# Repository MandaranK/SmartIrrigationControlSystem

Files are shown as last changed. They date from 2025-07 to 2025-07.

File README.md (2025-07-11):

# SmartIrrigationControlSystem
Designed on a custom-designed PCB using Proteus, integrating sensors, actuators, STM32, multivoltage rails, and display components to automate valve switching across irrigation zones. Used HAL to coordinate PWM, UART, ADC, and EXTI. Implemented timer-driven scheduling, RPM sensing, and interrupt-based logic.

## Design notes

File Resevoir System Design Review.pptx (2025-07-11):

## ECE298 Reservoir System Design Review

## Overview

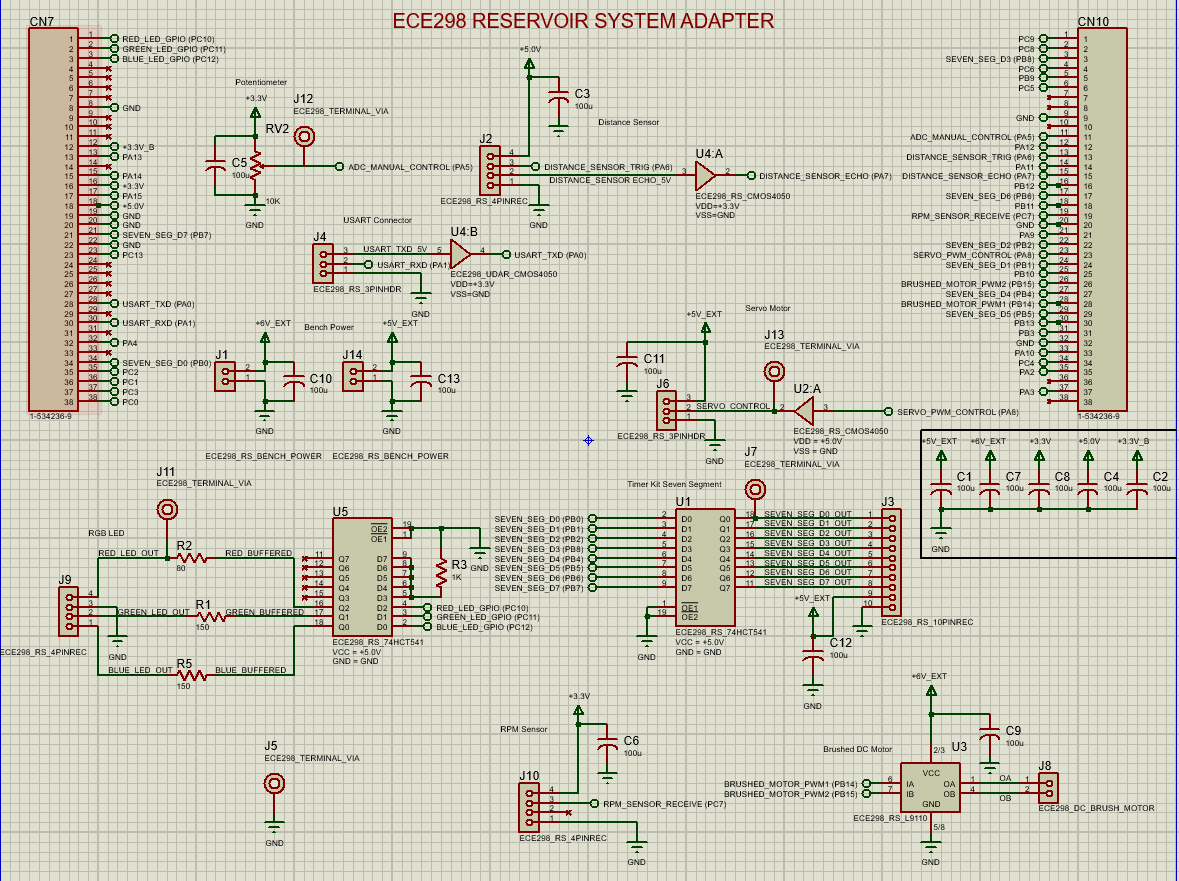
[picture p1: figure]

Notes: The reservoir system is powered by the 3.3V and 5V pins from the STM32, as well as 5V and 6V bench powers for the motors. All sensors and motors are controlled and utilized via the GPIO pins on the microcontroller. This design contains manual and terminal control for interfacing with the system, as well a display and RGB LED for visual aid. The pump for pumping water in and out of the reservoir is controlled by a brushed DC motor, and the distributer for distributing water to each of its 3 pipes is controlled with a servo. Lastly, the reservoir water level is monitored by an ultrasonic distance sensor.

## Bench Power

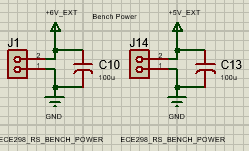
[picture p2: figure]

Operating Voltages: 5V and 6V external
Capacitors: 100 µF

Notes: There’s two connectors for external power here—6V and 5V—each with a ground. We added a capacitor across each supply to filter out noise and fluctuations from the bench power supply, ensuring steady voltage for the components. This setup helps prevent voltage drops or spikes, delivering stable power to maintain performance and protecting sensitive components.

## Power Decoupling

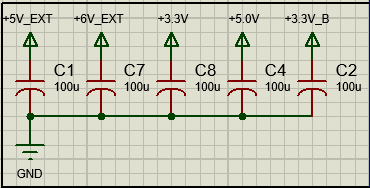
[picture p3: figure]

Operating Voltages : 3.3V, 5V, and 6V
Capacitors: 100 µF

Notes: The power decoupling uses 100 µF capacitors between ground and various voltage rails to stabilize power by filtering high-frequency noise and spikes. With different components drawing power at different times, these capacitors smooth fluctuations on each rail (5V, 6V, 3.3V). Placing them close to each rail provides localized filtering, minimizing interference or dips that could affect sensitive components.

## USART Connection

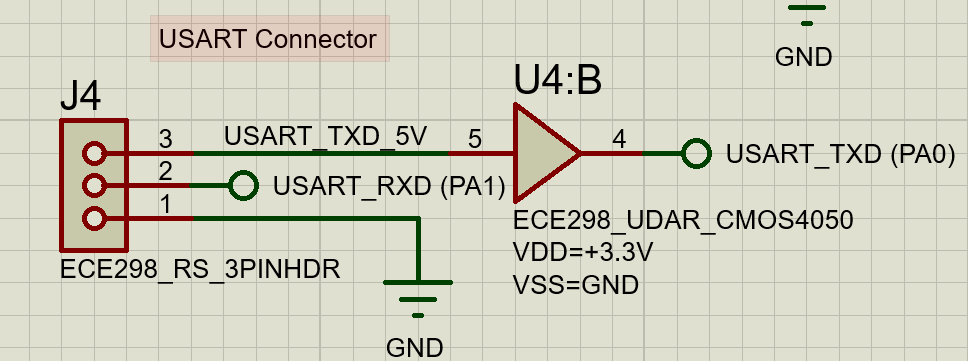
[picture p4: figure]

GPIO Pins: A0 (output), A1 (input)
Operating Voltage: 3.3V

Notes: Firstly we have the USART connnection. This allows the operator to interface
with the resevoir system via a terminal computer. This requires 2 lines: a transfer
line (TXD) and a receiving line (RXD). Since the STM32 only accepts a 3.3V input signal on
its GPIO pins, a buffer is used to translate the 5V high signal from the terminal to a 3.3V
signal on the transfer line. The USART connection can tolerate the 3.3V high signal from the MCU, so no buffer
is required on the receiving line

## Manual Control

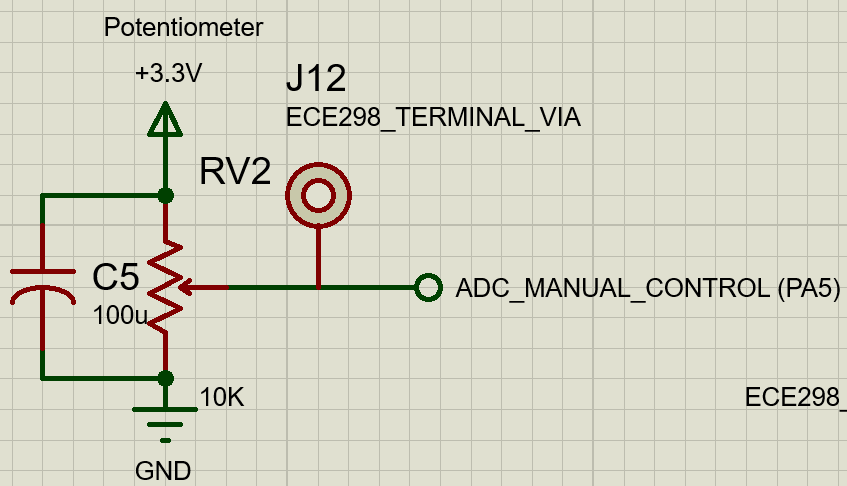
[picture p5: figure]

Output Voltage Range: 0V to 3.3V
Output Pin: A5 (ADC pin)

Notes: The potentiometer is used for manual control of the reservoir signal. A decoupled 3.3V source is applied across a variable potentiometer, which results in a variable output voltage in between 0 and 3.3V. Pin A5 is then used for its ADC capabilities to translate this voltage into an 8-bit number for use by the microcontroller. The test point can be used to ensure the correct range and values for this variable output voltage.

## Seven Segment Display Connection

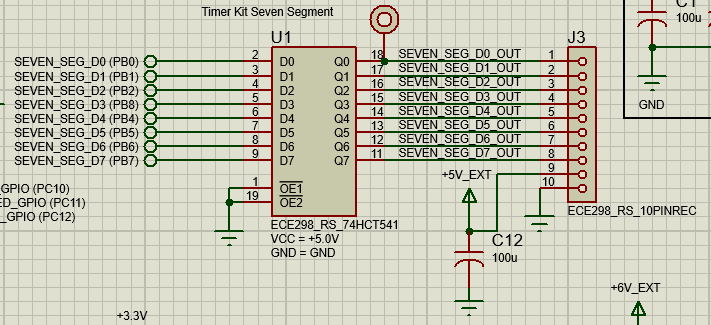
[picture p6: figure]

Timer Kit Operating Voltage: +5V
GPIO Output Pins: B0, B1, B2, B8, B4, B5, B6, B7

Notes: Next, the Timer Kit from Lab A is used for its seven-segment display. As the seven segment display requires a 5V high signal to operate, a buffer is used to translate the 3.3V signals from the MCU’s gpio pins to 5V signals. The connector to interface with the board contains 7 pins for each of the 7 segments, a 5V external pin for powering the board and a ground pin. Additionally, the test point allows the user to ensure the correct signal is reaching the timer board at all times

## RGB LED

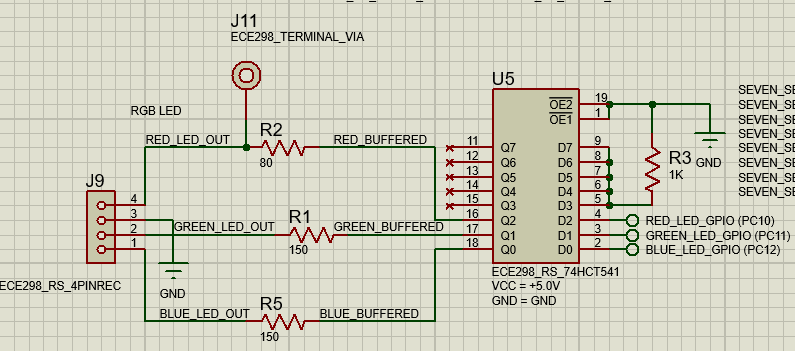
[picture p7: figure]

Operating Voltage: +5V
GPIO Output Pins: C10, C11, C12

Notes: This circuit controls an RGB LED using GPIO pins through a 74HCT541 buffer, with each LED color regulated by its own resistor (R2, R1, R5) to manage current and brightness. The buffer isolates and boosts the GPIO signals (PC10, PC11, PC12) to handle the LED’s current needs, protecting the microcontroller. Each LED is connected to a separate GPIO pin for smooth color mixing, with the buffer and LEDs powered by 5V for stable operation.

## Brushed DC Motor

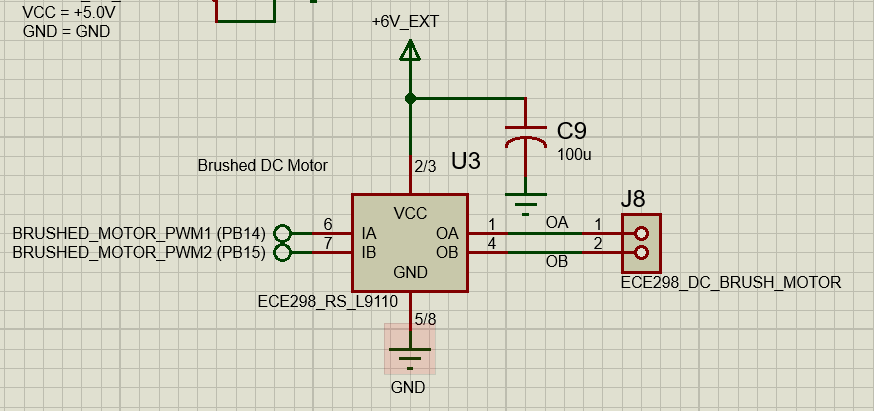
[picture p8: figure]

Operating Voltage: 6V external
GPIO Output Pins: B14, B15 (PWM pins)

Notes: This circuit controls a brushed DC motor using a motor driver powered by an external 6V supply, providing sufficient voltage without burdening the STM microcontroller. A capacitor smooths out voltage spikes, ensuring steady motor performance under load. The microcontroller’s PWM signals connect to the driver inputs, adjusting motor speed via duty cycle changes and reversing direction by toggling the inputs. The driver outputs connect to the motor terminals.

## RPM Sensor

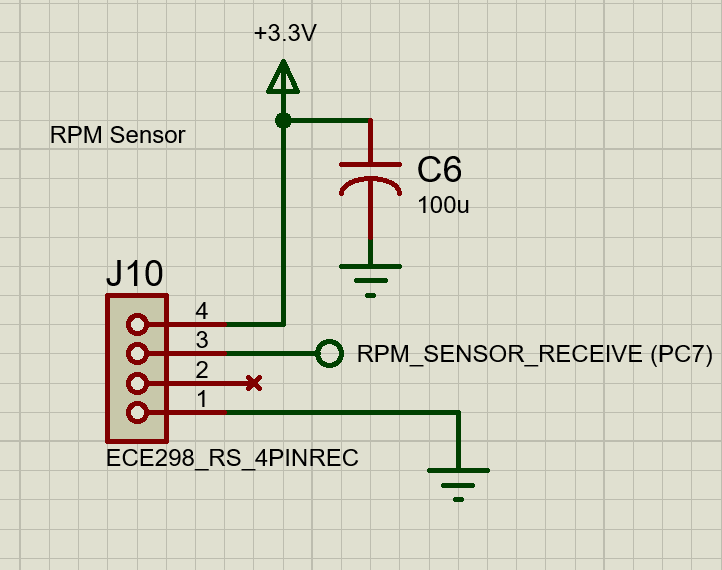
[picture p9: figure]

Operating Voltage: +3.3V
GPIO Input Pin: C7 (Receive pin)

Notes: This circuit reads RPM data from a sensor, with a stable 3.3V supply for accuracy. This 4-pin header contains a power, ground, and signal, with a 100 µF capacitor (C6) smoothing any voltage fluctuations. The sensor’s output is routed to the "RPM_SENSOR_RECEIVE" pin (PC7) for clean, reliable RPM data.

## Servo Control

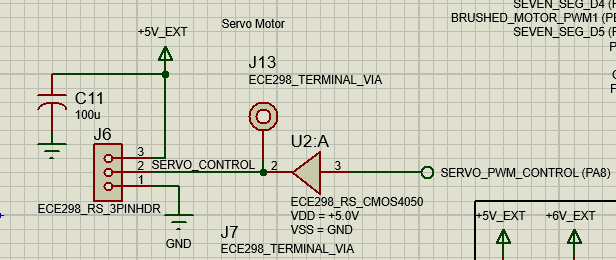
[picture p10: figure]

Operating Voltage: 5V external
GPIO Input Pin: A8 (PWM pin)

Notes: Moving on we have the servo that controls which pipe the reservoir is connected to. The servo is powered by the decoupled external 5V bench power to reduce noise. Pin A8 on the STM32 supports PWM outputs, so its 3.3V high signal is translated to a 5V high signal for PWM motor control. The additional test point can be used to monitor this translated PWM signal. The connector allows for wire connections to this translated PWM signal, the external bench power, and ground.

## Distance Sensor

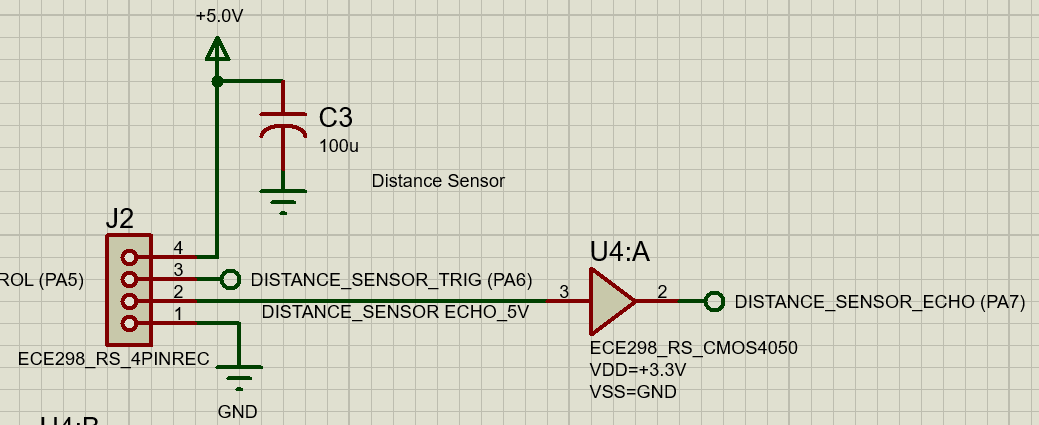
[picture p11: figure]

Operating Voltage: +5V
GPIO Pins: A6 (output), A7 (input)

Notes: Lets continue with the HCSR04 distance sensor, which monitors the water level of the reservoir. The sensor has a trigger signal for starting the collection of data, and an echo signal for the transfer of this data. A buffer is used to translate the 5V echo signal of the sensor to a 3.3V signal that complies with the STM32’s gpio pins. Since the sensor can tolerate the 3.3V high signal from the MCU, no buffer is needed. A 4 pin connector connects the decoupled 5V supply voltage, trigger, echo, and ground reference signals to the sensor.

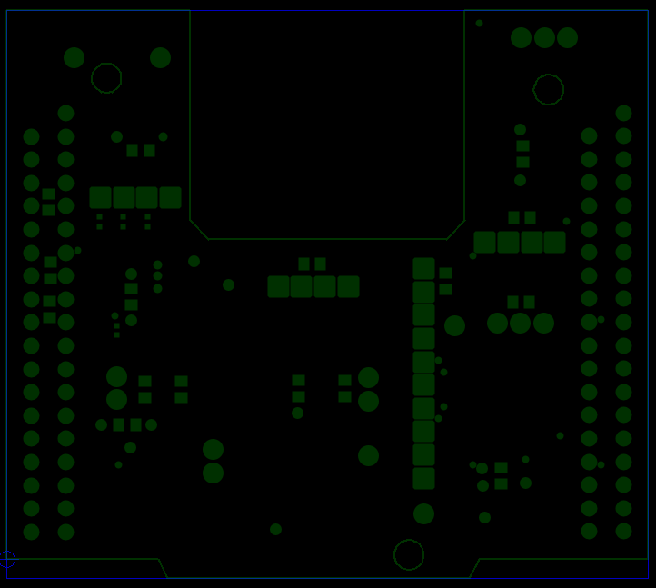
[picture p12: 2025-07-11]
Project Design/Images/BottomResist.PNG

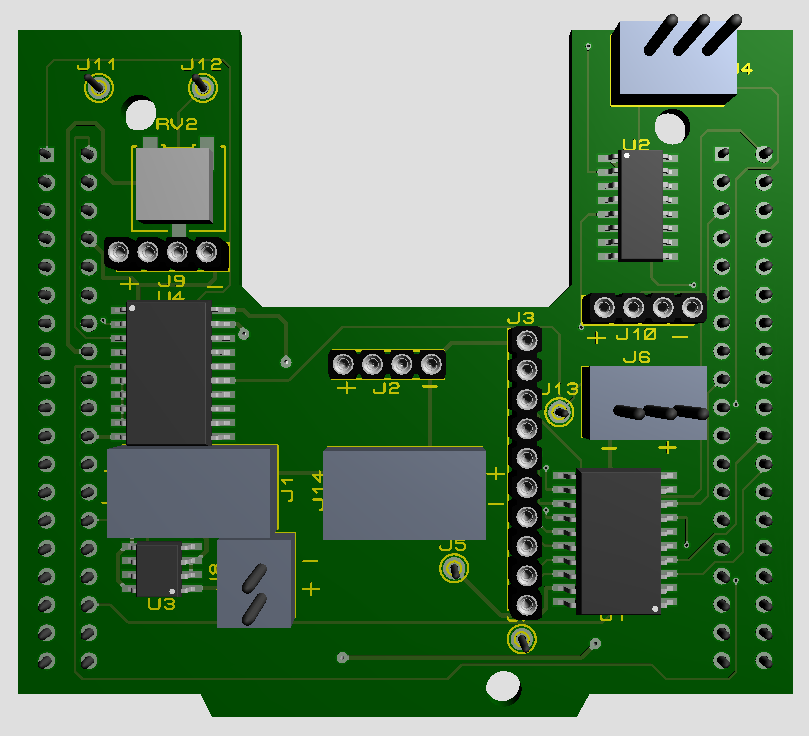
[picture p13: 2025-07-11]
Project Design/Images/3D_Model_Top.PNG

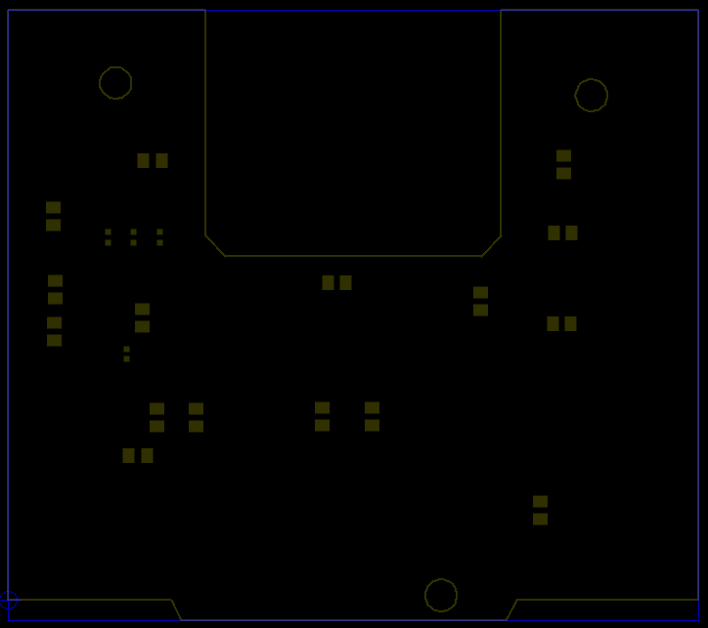
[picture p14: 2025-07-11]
Project Design/Images/BottomPaste.PNG

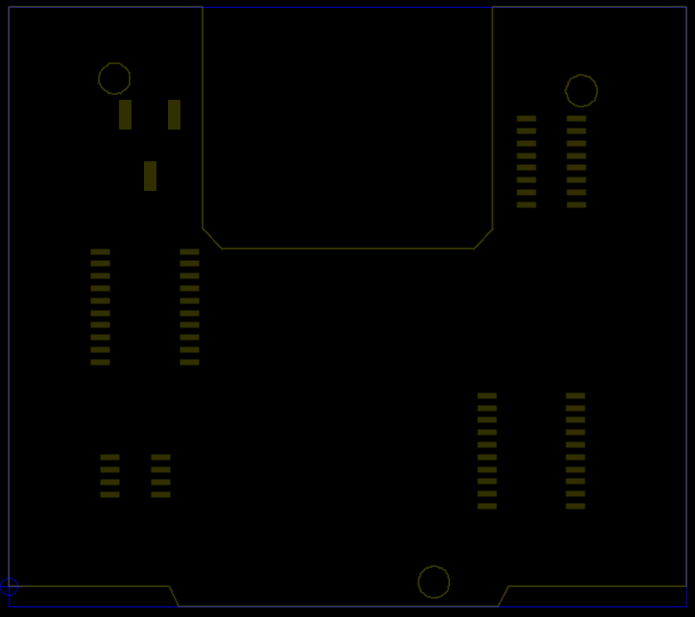
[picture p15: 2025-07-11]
Project Design/Images/TopPast.PNG

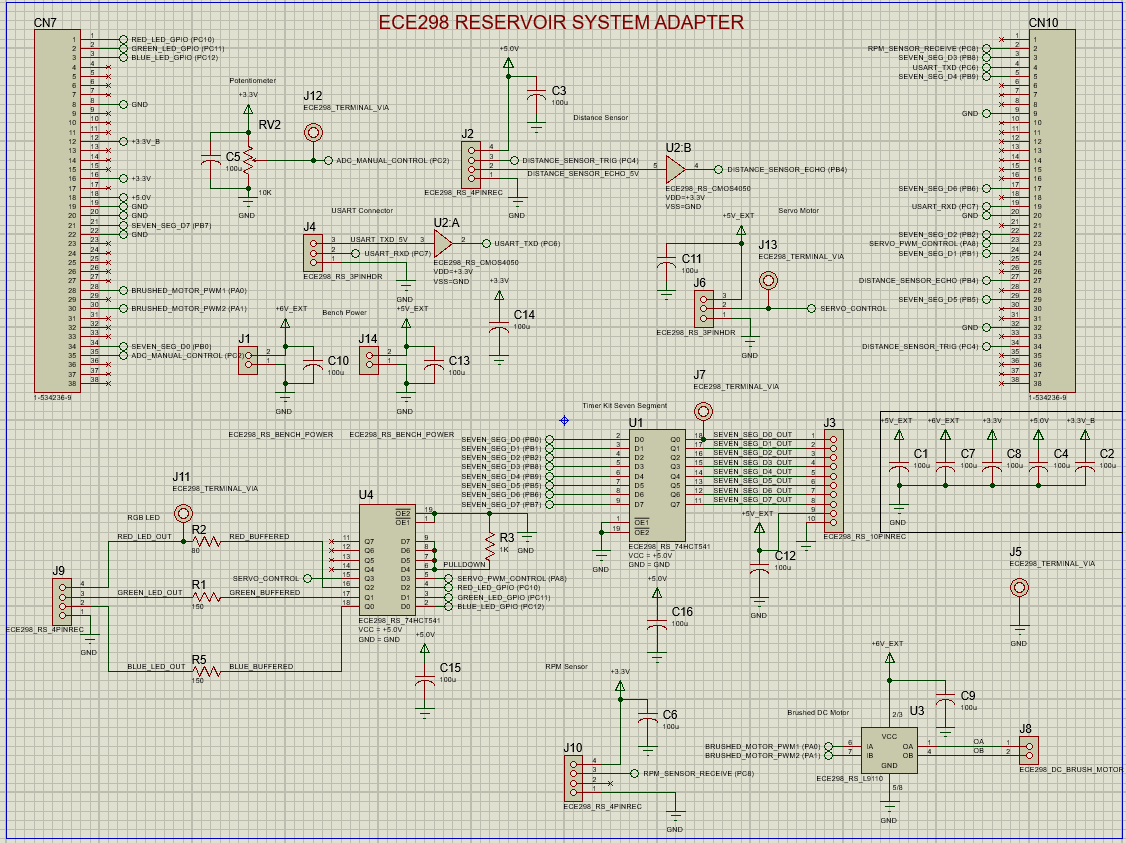
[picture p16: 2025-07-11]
FinalSchematic.PNG

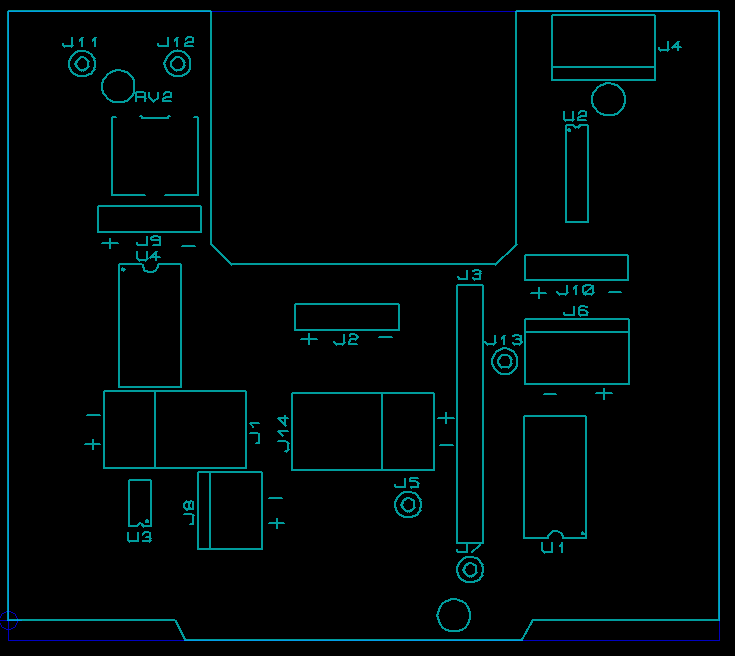
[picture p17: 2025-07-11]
Project Design/Images/TopSilk.PNG

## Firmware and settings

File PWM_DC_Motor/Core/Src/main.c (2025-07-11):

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
/* Includes ------------------------------------------------------------------*/
#include "main.h"

/* USER CODE BEGIN Includes */
#include <string.h>
#include <stdio.h>
/* USER CODE END Includes */

ADC_HandleTypeDef hadc1;

TIM_HandleTypeDef htim2;
TIM_HandleTypeDef htim3;
TIM_HandleTypeDef htim4;

UART_HandleTypeDef huart2;
UART_HandleTypeDef huart6;

void SystemClock_Config(void);
static void MX_GPIO_Init(void);
static void MX_USART2_UART_Init(void);
static void MX_TIM3_Init(void);
static void MX_TIM2_Init(void);
static void MX_USART6_UART_Init(void);
static void MX_ADC1_Init(void);
static void MX_TIM4_Init(void);
/* USER CODE BEGIN PFP */
//Global Variables
uint8_t txd_msg_buffer[64] = {0};
uint8_t wall_clock_hr_update_flag = 0;
volatile uint8_t clock_hours = 0;
volatile uint8_t clock_mins = 0;
volatile uint8_t clock_secs = 0;
uint8_t rpm_tick_count = 0;



//Functions
static void ADC_Select_CH(int CH);
void ADC_Select_CH(int CH)
{
ADC_ChannelConfTypeDef sConfig = {0};
switch(CH)
{
case 0:
sConfig.Channel = ADC_CHANNEL_0;
sConfig.Rank = 1;
if (HAL_ADC_ConfigChannel(&hadc1, &sConfig) != HAL_OK)
{
Error_Handler();
}
break;
case 1:
sConfig.Channel = ADC_CHANNEL_1;
sConfig.Rank = 1;
if (HAL_ADC_ConfigChannel(&hadc1, &sConfig) != HAL_OK)
{
Error_Handler();
}
break;
case 2:
sConfig.Channel = ADC_CHANNEL_2;
sConfig.Rank = 1;
if (HAL_ADC_ConfigChannel(&hadc1, &sConfig) != HAL_OK)
{
Error_Handler();
}
break;
case 3:
sConfig.Channel = ADC_CHANNEL_3;
sConfig.Rank = 1;
if (HAL_ADC_ConfigChannel(&hadc1, &sConfig) != HAL_OK)
{
Error_Handler();
}
break;
case 4:
sConfig.Channel = ADC_CHANNEL_4;
sConfig.Rank = 1;
if (HAL_ADC_ConfigChannel(&hadc1, &sConfig) != HAL_OK)
{
Error_Handler();
}
break;
case 5:
sConfig.Channel = ADC_CHANNEL_5;
sConfig.Rank = 1;
if (HAL_ADC_ConfigChannel(&hadc1, &sConfig) != HAL_OK)
{
Error_Handler();
}
break;
case 6:
sConfig.Channel = ADC_CHANNEL_6;
sConfig.Rank = 1;
if (HAL_ADC_ConfigChannel(&hadc1, &sConfig) != HAL_OK)
{
Error_Handler();
}
break;
case 7:
sConfig.Channel = ADC_CHANNEL_7;
sConfig.Rank = 1;
if (HAL_ADC_ConfigChannel(&hadc1, &sConfig) != HAL_OK)
{
Error_Handler();
}
break;
case 8:
sConfig.Channel = ADC_CHANNEL_8;
sConfig.Rank = 1;
if (HAL_ADC_ConfigChannel(&hadc1, &sConfig) != HAL_OK)
{
Error_Handler();
}
break;
case 9:
sConfig.Channel = ADC_CHANNEL_9;
sConfig.Rank = 1;
if (HAL_ADC_ConfigChannel(&hadc1, &sConfig) != HAL_OK)
{
Error_Handler();
}
break;
case 10:
sConfig.Channel = ADC_CHANNEL_10;
sConfig.Rank = 1;
if (HAL_ADC_ConfigChannel(&hadc1, &sConfig) != HAL_OK)
{
Error_Handler();
}
break;
case 11:
sConfig.Channel = ADC_CHANNEL_11;
sConfig.Rank = 1;
if (HAL_ADC_ConfigChannel(&hadc1, &sConfig) != HAL_OK)
{
Error_Handler();
}
break;
case 12:
sConfig.Channel = ADC_CHANNEL_12;
sConfig.Rank = 1;
if (HAL_ADC_ConfigChannel(&hadc1, &sConfig) != HAL_OK)
{
Error_Handler();
}
break;
case 13:
sConfig.Channel = ADC_CHANNEL_13;
sConfig.Rank = 1;
if (HAL_ADC_ConfigChannel(&hadc1, &sConfig) != HAL_OK)
{
Error_Handler();
}
break;
case 14:
sConfig.Channel = ADC_CHANNEL_14;
sConfig.Rank = 1;
if (HAL_ADC_ConfigChannel(&hadc1, &sConfig) != HAL_OK)
{
Error_Handler();
}
break;
case 15:
sConfig.Channel = ADC_CHANNEL_15;
sConfig.Rank = 1;
if (HAL_ADC_ConfigChannel(&hadc1, &sConfig) != HAL_OK)
{
Error_Handler();
}
break;
}
}

void DIGITS_Display(uint8_t NUM)
		{
			 uint8_t DIGIT_A = NUM/10;
			 uint8_t DIGIT_B = NUM%10;
			 uint8_t DIGITA_VAL = 0x0F & DIGIT_A; //mask off higher4 bits
			 int Abit0 = (DIGITA_VAL ) & 1;  	// extract Abit0 of the 4-bit value
			 int Abit1 = (DIGITA_VAL >> 1) & 1;  // extract Abit1 of the 4-bit value
			 int Abit2 = (DIGITA_VAL >> 2) & 1;  // extract Abit2 of the 4-bit value
			 int Abit3 = (DIGITA_VAL >> 3) & 1;  // extract Abit3 of the 4-bit value

			 uint8_t DIGITB_VAL = 0x0F & DIGIT_B; //mask off higher4 bits
			 int Bbit0 = (DIGITB_VAL ) & 1;  	// extract Bbit0 of the 4-bit value
			 int Bbit1 = (DIGITB_VAL >> 1) & 1;  // extract Bbit1 of the 4-bit value
			 int Bbit2 = (DIGITB_VAL >> 2) & 1;  // extract Bbit2 of the 4-bit value
			 int Bbit3 = (DIGITB_VAL >> 3) & 1;  // extract Bbit3 of the 4-bit value

			 if (Abit0 == (0))
			 {
				 HAL_GPIO_WritePin(GPIOB, BCD_D0_Pin, GPIO_PIN_RESET);
			 }
			 else
			 {
				 HAL_GPIO_WritePin(GPIOB, BCD_D0_Pin, GPIO_PIN_SET);

			 }
			 if (Abit1 == (0))
			 {
				 HAL_GPIO_WritePin(GPIOB, BCD_D1_Pin, GPIO_PIN_RESET);
			 }
			 else
			 {
				 HAL_GPIO_WritePin(GPIOB, BCD_D1_Pin, GPIO_PIN_SET);

			 }
			 if (Abit2 == (0))
			 {
				 HAL_GPIO_WritePin(GPIOB, BCD_D2_Pin, GPIO_PIN_RESET);
			 }
			 else
			 {
				 HAL_GPIO_WritePin(GPIOB, BCD_D2_Pin, GPIO_PIN_SET);

			 }
			 if (Abit3 == (0))
			 {
				 HAL_GPIO_WritePin(GPIOB, BCD_D3_Pin, GPIO_PIN_RESET);
			 }
			 else
			 {
				 HAL_GPIO_WritePin(GPIOB, BCD_D3_Pin, GPIO_PIN_SET);

			 }


			 if (Bbit0 == (0))
			 {
				 HAL_GPIO_WritePin(GPIOB, BCD_D4_Pin, GPIO_PIN_RESET);
			 }
			 else
			 {
				 HAL_GPIO_WritePin(GPIOB, BCD_D4_Pin, GPIO_PIN_SET);

			 }
			 if (Bbit1 == (0))
			 {
				 HAL_GPIO_WritePin(GPIOB, BCD_D5_Pin, GPIO_PIN_RESET);
			 }
			 else
			 {
				 HAL_GPIO_WritePin(GPIOB, BCD_D5_Pin, GPIO_PIN_SET);

			 }
			 if (Bbit2 == (0))
			 {
				 HAL_GPIO_WritePin(GPIOB, BCD_D6_Pin, GPIO_PIN_RESET);
			 }
			 else
			 {
				 HAL_GPIO_WritePin(GPIOB, BCD_D6_Pin, GPIO_PIN_SET);

			 }
			 if (Bbit3 == (0))
			 {
				 HAL_GPIO_WritePin(GPIOB, BCD_D7_Pin, GPIO_PIN_RESET);
			 }
			 else
			 {
				 HAL_GPIO_WritePin(GPIOB, BCD_D7_Pin, GPIO_PIN_SET);

			 }
		}
/* USER CODE END PFP */

/**
  * @brief  The application entry point.
  * @retval int
  */
int main(void)
{

  /* USER CODE BEGIN 1 */

	//Variables
	uint8_t txd_msg_buffer[64] = {0};
	  clock_hours = 0;
	  clock_mins = 0;
	  clock_secs = 0;

  /* USER CODE END 1 */

  /* MCU Configuration--------------------------------------------------------*/

  /* Reset of all peripherals, Initializes the Flash interface and the Systick. */
  HAL_Init();

  /* Configure the system clock */
  SystemClock_Config();

  /* Initialize all configured peripherals */
  MX_GPIO_Init();
  MX_USART2_UART_Init();
  MX_TIM3_Init();
  MX_TIM2_Init();
  MX_USART6_UART_Init();
  MX_ADC1_Init();
  MX_TIM4_Init();
  /* USER CODE BEGIN 2 */
//HAL_TIM_Base_Init(&htim2);

HAL_TIM_PWM_Start(&htim2,TIM_CHANNEL_1);
HAL_TIM_PWM_Start(&htim2,TIM_CHANNEL_2);


TIM2->PSC = 0;
TIM2->ARR = 60000;
TIM2->CCR1 =50000;
TIM2->CCR2 =0;

HAL_TIM_Base_Start_IT(&htim4);

  /* USER CODE END 2 */

  /* Infinite loop */
  /* USER CODE BEGIN WHILE */
  while (1)
  {
	  //RPM/Motor Control
//	  sprintf((char*)txd_msg_buffer,"RPM TICK COUNT: %d \r\n", rpm_tick_count);
//	  HAL_UART_Transmit(&huart6, txd_msg_buffer, strlen((char*)txd_msg_buffer),1000);

	  //ADC
//	  ADC_Select_CH(12);
//	  HAL_ADC_Start(&hadc1);
//	  HAL_ADC_PollForConversion(&hadc1,1000);
//	  uint8_t ADC_CH12 = HAL_ADC_GetValue(&hadc1);
//	  HAL_ADC_Stop(&hadc1);
//
//	  sprintf((char*)txd_msg_buffer,"DIGITIZED ANALOG VALUE FOR CH12: %d \r \n", ADC_CH12);
//	  HAL_UART_Transmit(&huart6,txd_msg_buffer,strlen((char*)txd_msg_buffer),1000);
//	  HAL_Delay(1000);

	  //RGB
	  HAL_GPIO_WritePin(GPIOC, RED_LED_Pin,GPIO_PIN_SET);
	  HAL_GPIO_WritePin(GPIOC, GREEN_LED_Pin,GPIO_PIN_RESET);
	  HAL_GPIO_WritePin(GPIOC, BLUE_LED_Pin,GPIO_PIN_RESET);

	  //BCD Display
	  DIGITS_Display(23);

	  //Wall Clock
	  sprintf((char*)txd_msg_buffer,"Minutes: %d \r\n", clock_mins);
	  HAL_UART_Transmit(&huart6, txd_msg_buffer, strlen((char*)txd_msg_buffer),1000);
	  sprintf((char*)txd_msg_buffer,"Secs: %d \r\n", clock_secs);
	  HAL_UART_Transmit(&huart6, txd_msg_buffer, strlen((char*)txd_msg_buffer),1000);
	  HAL_Delay(1000);


    /* USER CODE END WHILE */

    /* USER CODE BEGIN 3 */
  }
  /* USER CODE END 3 */
}

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
/* USER CODE BEGIN 4 */
void HAL_GPIO_EXTI_Callback(uint16_t GPIO_Pin)
{
	if(GPIO_Pin == RPM_TICK_Pin)
	{
		rpm_tick_count += 1;
	}
}
void HAL_TIM_PeriodElapsedCallback(TIM_HandleTypeDef *htim)
{
	if((htim->Instance == TIM4))
	{
		wall_clock_hr_update_flag = 0;
		clock_secs += 1;
	}
	if((clock_secs == 60))
	{
		clock_mins += 1;
		clock_secs = 0;
	}
	if((clock_mins == 60 ))
	{
		clock_hours += 1;
		clock_mins = 0;
	}
	wall_clock_hr_update_flag = 1;

}
/* USER CODE END 4 */
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


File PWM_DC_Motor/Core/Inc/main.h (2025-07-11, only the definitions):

#define B1_Pin GPIO_PIN_13
#define B1_GPIO_Port GPIOC
#define B1_EXTI_IRQn EXTI15_10_IRQn
#define USART_TX_Pin GPIO_PIN_2
#define USART_TX_GPIO_Port GPIOA
#define USART_RX_Pin GPIO_PIN_3
#define USART_RX_GPIO_Port GPIOA
#define LD2_Pin GPIO_PIN_5
#define LD2_GPIO_Port GPIOA
#define BCD_D0_Pin GPIO_PIN_0
#define BCD_D0_GPIO_Port GPIOB
#define BCD_D1_Pin GPIO_PIN_1
#define BCD_D1_GPIO_Port GPIOB
#define BCD_D2_Pin GPIO_PIN_2
#define BCD_D2_GPIO_Port GPIOB
#define RPM_TICK_Pin GPIO_PIN_8
#define RPM_TICK_GPIO_Port GPIOC
#define RPM_TICK_EXTI_IRQn EXTI9_5_IRQn
#define TMS_Pin GPIO_PIN_13
#define TMS_GPIO_Port GPIOA
#define TCK_Pin GPIO_PIN_14
#define TCK_GPIO_Port GPIOA
#define RED_LED_Pin GPIO_PIN_10
#define RED_LED_GPIO_Port GPIOC
#define GREEN_LED_Pin GPIO_PIN_11
#define GREEN_LED_GPIO_Port GPIOC
#define BLUE_LED_Pin GPIO_PIN_12
#define BLUE_LED_GPIO_Port GPIOC
#define SWO_Pin GPIO_PIN_3
#define SWO_GPIO_Port GPIOB
#define BCD_D4_Pin GPIO_PIN_4
#define BCD_D4_GPIO_Port GPIOB
#define BCD_D5_Pin GPIO_PIN_5
#define BCD_D5_GPIO_Port GPIOB
#define BCD_D6_Pin GPIO_PIN_6
#define BCD_D6_GPIO_Port GPIOB
#define BCD_D7_Pin GPIO_PIN_7
#define BCD_D7_GPIO_Port GPIOB
#define BCD_D3_Pin GPIO_PIN_8
#define BCD_D3_GPIO_Port GPIOB

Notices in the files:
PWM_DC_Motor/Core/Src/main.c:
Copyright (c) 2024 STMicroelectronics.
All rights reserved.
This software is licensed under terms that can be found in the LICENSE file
